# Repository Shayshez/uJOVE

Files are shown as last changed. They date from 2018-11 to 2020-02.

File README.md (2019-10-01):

# uJOVE
# CC BY-NC-SA 4.0
## Micro version of JOVE - Multimode filter, originally by System 80
## Warning for DIY beginners - this project is a hard to build with dense PCB and low pitch ic's which requires experience in SMD soldering.
### If you care about this project - DO NOT SELL ASSEMBLED MODULES, Build only for your own use!

Interactive BOM: http://diy.plum-audio.com/projects/uJove/iBom/

Plum Audio uJove is 8hp version of Jove - Multimode filter By System 80 that is inspired by the Roland Jupiter 6 filter.

uJuve is exactly the same circuit as the original 14 hp Juve with the same amazing sound. 

2 extra modifications have been added to increase the sound variety:

1. When no jack is plugged in to input 2 Positive feedback from the output to input 2 is activated. the feedback level can be controlled by LEVEL 2 knob.
2. Input 2 level knob can add 6dB of gain, 0dB on the middle, +6dB (clipping) when fully clockwise. 

4 Leds of the original 14 hp Jove replaced by one RGB Led

Modes colours:
RED - LP24 , ORANGE - LP12 , BLUE - BP , GREEN - HP

### About Positive Feedback:
Resonance = inverted feedback 

Positive feedback should distort the signal.

In LP2/4 modes (red/orange) the positive feedback alone can make pulses.

it’s better to mix between positive and negative feedback to achieve distorted worm sound.
Also try to use input 2 in LP modes and the positive feedback become clipper (attenuation until middle position of the knob and clipping from middle position)

The positive feedback sounds much better in BP/HP modes (blue/green) to achive great distortion.

uJove is available only as DIY project, for pcb's and panels: https://pushermanproductions.com/product/plum-audio-ujove-pcb-and-8hp-aluminium-panel/

Assembling Video (Part 1): https://www.youtube.com/watch?v=_F6PMT1OO5I

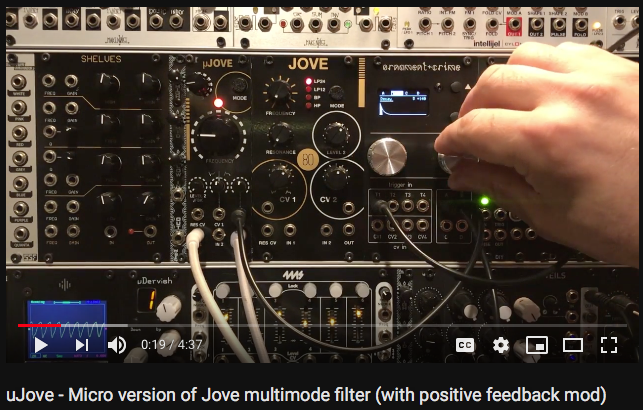
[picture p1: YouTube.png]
uJove at YouTube (https://youtu.be/qpCmzDNtNPw)


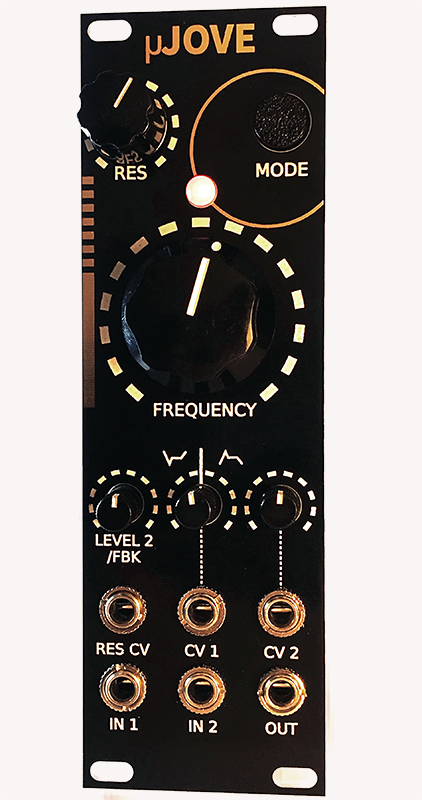
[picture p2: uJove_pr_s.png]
Image of uJOVE


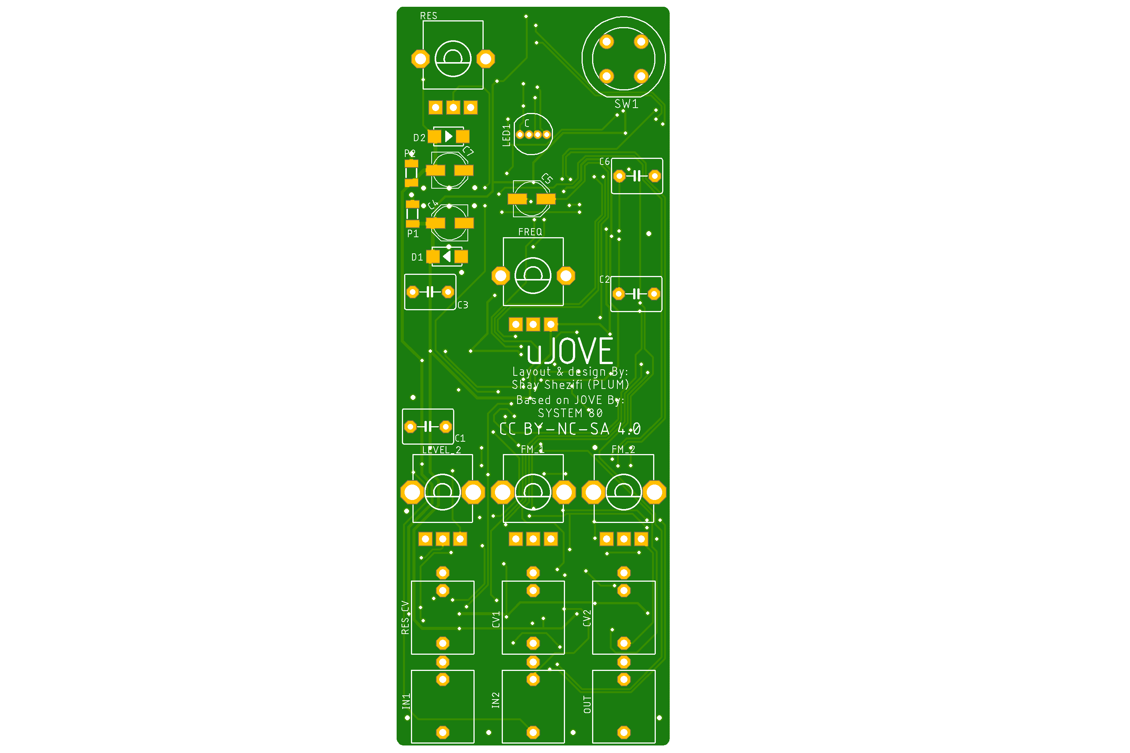
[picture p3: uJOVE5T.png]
Image of uJOVE


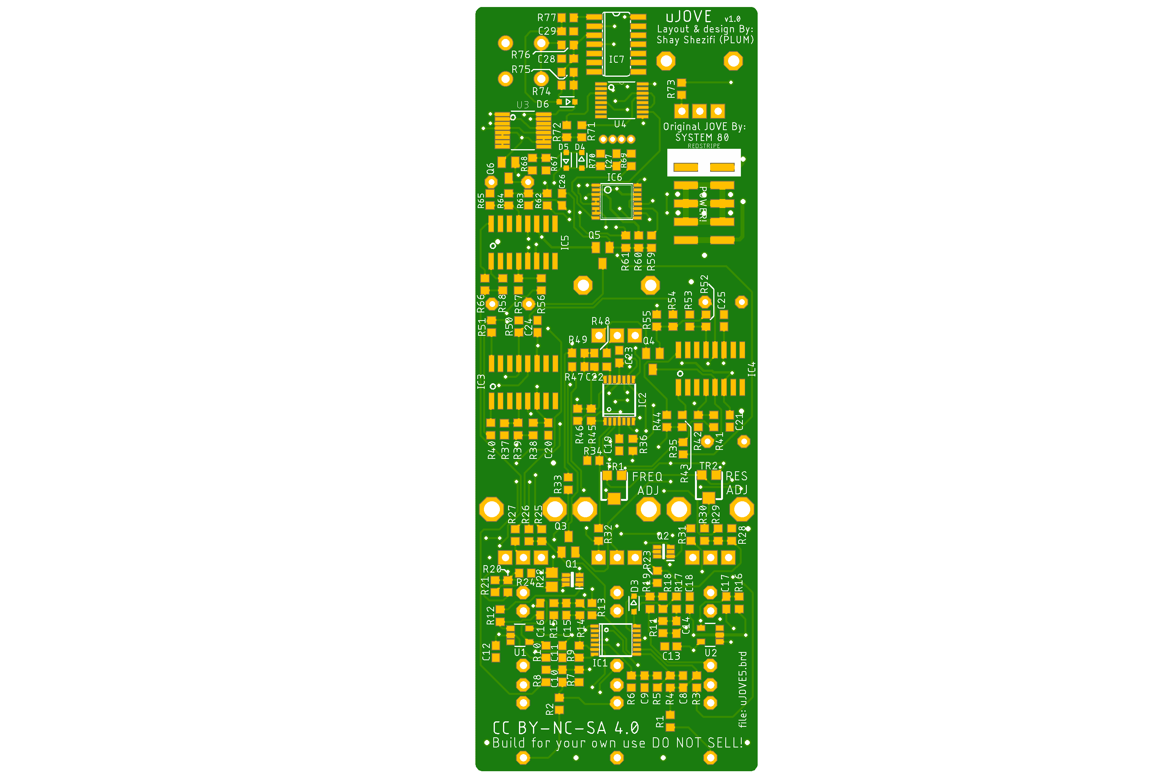
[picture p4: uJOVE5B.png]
Image of uJOVE


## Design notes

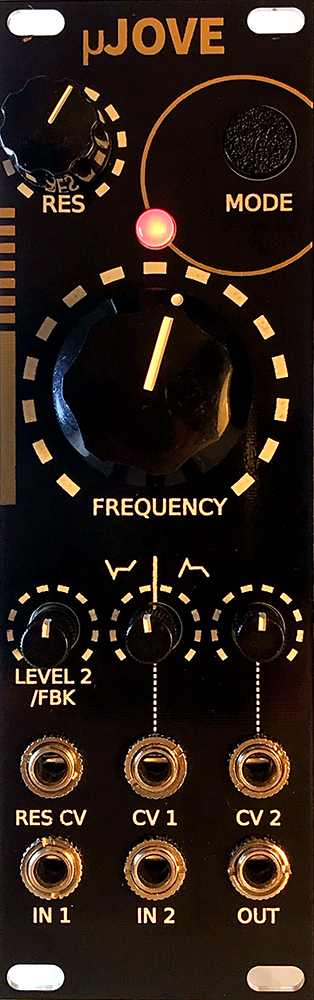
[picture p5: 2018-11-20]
uJove_mg.png

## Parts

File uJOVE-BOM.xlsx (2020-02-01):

 | THIS BOM IS FOR BOARD V1.2
 | Interactive BOM: http://diy.plum-audio.com/projects/uJove/iBom/
Qty | Parts | Value | Device | Package | Mouser referance | Description
 | CAPS
2 | C17, C28 | 4.7pF | C-USC0603 | C0603 | CC0603CRNPO9BN4R7 | CAPACITOR, American symbol
4 | C10, C12, C16, C24 | 22pF | C-USC0603 | C0603 | C0603C220J5G7411 | CAPACITOR, American symbol
2 | C11, C29 | 33pF | C-USC0603 | C0603 | C0603C330J5GACTU | CAPACITOR, American symbol
2 | C19, C18 | 47pF | C-USC0603 | C0603 | C0603C470J5GACTU | CAPACITOR, American symbol
12 | C8, C9, C13, C14, C15, C20, C21, C22, C23, C25, C26, C27 | 100n | C-USC0603 | C0603 | C0603C104M5RACTU | CAPACITOR, American symbol
2 | C30, C31 | 0.47uF | C-USC0603 | C0603 | CGA3E3X5R1H474MB | CAPACITOR, American symbol
1 | C5 | 10uF | CPOL-USC | PANASONIC_C | UUQ1E100MCL1GB | POLARIZED CAPACITOR, American symbol
2 | C4, C7 | 10uF | CPOL-USC | PANASONIC_C | EEE-1EA100SR | POLARIZED CAPACITOR, American symbol
4 | C1, C2, C3, C6 | 330pF | C5/5 | C5B5 | PFR5331J100J11L4 | Polypropylene FILM CAPACITOR 5mm
 | RESISTORS
2 | R76, R77 | 330 | R-US_R0603 | R0603 | RC0603FR-07330RL | RESISTOR, American symbol
6 | R37, R42, R50, R53, R58, R66 | 560 | R-US_R0603 | R0603 | RC0603FR-07560RL | RESISTOR, American symbol
1 | R24 | 820 | R-US_R0603 | R0603 | RC0603FR-07820RL | RESISTOR, American symbol
2 | R2, R28 | 1.0k | R-US_R0603 | R0603 | RC0603FR-071KL | RESISTOR, American symbol
2 | R12, R31 | 1.5k | R-US_R0603 | R0603 | RC0603FR-071K5L | RESISTOR, American symbol
1 | R21 | 1.8k | R-US_R0603 | R0603 | RC0603FR-071K8L | RESISTOR, American symbol
1 | R33 | 4.7k | R-US_R0603 | R0603 | RC0603FR-074K7L | RESISTOR, American symbol
1 | R20 | 5.6k | R-US_R0603 | R0603 | RC0603FR-105K6L | RESISTOR, American symbol
1 | R6 | 8.2k | R-US_R0603 | R0603 | RC0603FR-078K2L | RESISTOR, American symbol
5 | R60, R63, R67, R72, R73 | 10k | R-US_R0603 | R0603 | RC0603FR-0710KL | RESISTOR, American symbol
6 | R40, R43, R44, R51, R56, R59 | 18k | R-US_R0603 | R0603 | RC0603FR-0718KL | RESISTOR, American symbol
7 | R13, R15, R38, R55, R61, R70, R75 | 33k | R-US_R0603 | R0603 | RC0603FR-0733KL | RESISTOR, American symbol
5 | R3, R4, R5, R49, R68 | 47k | R-US_R0603 | R0603 | RC0603FR-0747KL | RESISTOR, American symbol
3 | R26, R35, R71 | 56k | R-US_R0603 | R0603 | RC0603FR-0756KL | RESISTOR, American symbol
6 | R39, R41, R52, R54, R57, R65 | 68k | R-US_R0603 | R0603 | RC0603FR-0768KL | RESISTOR, American symbol
17 | R1, R8, R9, R11, R14, R17, R18, R19, R27, R32, R34, R36, R45, R62, R64, R69, R74 | 100k | R-US_R0603 | R0603 | RC0603FR-07100KL | RESISTOR, American symbol
1 | R29 | 110k | R-US_R0603 | R0603 | RC0603FR-07110KL | RESISTOR, American symbol
1 | R23 | 150k | R-US_R0603 | R0603 | RC0603FR-07150KL | RESISTOR, American symbol
2 | R47, R48 | 200k | R-US_R0603 | R0603 | RC0603FR-07200KL | RESISTOR, American symbol
1 | R25 | 270k | R-US_R0603 | R0603 | RC0603FR-07270KL | RESISTOR, American symbol
1 | R7 | 330k | R-US_R0603 | R0603 | RC0603FR-07330KL | RESISTOR, American symbol
1 | R46 | 680K | R-US_R0603 | R0603 | RC0603FR-07680KL | RESISTOR, American symbol
1 | R30 | 1.0M | R-US_R0603 | R0603 | RC0603FR-071ML | RESISTOR, American symbol
2 | R10, R16 | 1.5M | R-US_R0603 | R0603 | RC0603FR-071M5L | RESISTOR, American symbol
1 | R22 | 10k NTC | R-US_R0805 | R0805 | NCP21XV103J03RA | RESISTOR, American symbol
 | Note1: R71 & R72 = led brightness, R71 for green, R72 for red & blue.
 | Note2: R3 = Gain of input 2 and feadback, 47k for 0dB at pot middle position and +6db clipping at fully clockwise, it can be between 47K-100K (100k = without gain, 0dB at fully clockwise)
 | DIODES / TRANSISTORS
2 | P1, P2 | PTCSMD | PTCSMD (or 4.7R 1206 resistor) | PTC-1206 | 1206L035/16YR | Resettable Fuse PTC
4 | D3, D4, D5, D6 | 1N914BWS | DIODE-SOD323-R | SOD323-R | 512-1N914BWS | DIODE
2 | D1, D2 | S1BB | DIODE-GEN-PURPOSE-1KV-1A(DO-214AC) | DO-214AC | 621-S1BB-F | 304010013
2 | Q1, Q2 | BCM857BS | BCM857BS | SOT65P210X110-6N | BC857BS-7-F | NEXPERIA - BCM857BS - TRANSISTOR, MATCHED, SOT-363
4 | Q3, Q4, Q5, Q6 | MMBFJ112MMBFJ112 | MMBFJ112MMBFJ112 | SOT23 | 512-MMBFJ112 | * NO STOCK AT MOUSER, CAN BE FOUND HERE: https://www.aliexpress.com/item/FREE-SHIPPING-SOT23-GR-MMBFJ112-20PCS-in-Stock/32314708542.html
 | IC'S
1 | IC8 | 40106D | 40106D | SO14 | CD40106BM96 | Hex SCHMITT TRIGGER
1 | U4 | CD4052BPWR | CD4052BPWR | SOP65P640X120-16N | CD4052BPWR | single 8-Channel multiplexer
2 | U1, U2 | TS321ILT | TS321IDBV | SOT23-5 | TS321ILT
1 | IC3 | TL074TSSOP14 | TL074TSSOP14 | TSSOP14 | TL074CPWR | OP AMP
2 | IC1, IC2 | TL072 TSSOP8 | TL072TL072_TSSOP8 | TSSOP8 | TL072CPWR | OP AMP
1 | IC7 | DQDG409DQ-T1-E3 | DG409DQ-T1-E3 | TSSOP16 | DG409DQ-E3 | ANALOG MULTIPLEXER
3 | IC4, IC5, IC6 | OTA_LM13700M | OTA_LM13700M | OTA_SO16 | LM13700MX/NOPB | Dual OTA with buffers
1 | U3 | CD4027BPWRPW16-M | CD4027BPWRPW16-M | PW16-M | CD4027BPWR
 | TH / MISC
2 | TR1, TR2 | 100K | TC33X-2-104E | TC33X-2 | TC33X-2-104E | Cermet 3mm SMT trimmer,0.1W 100k Bourns TC33 Series SMD Cermet Trimmer Resistor with Solder Pad Terminations, 100k 25% 1/10W 250ppm/C Top Adjust
1 | LED1 | LED-TRICOLOR-THROUGHHOLE | LED-TRICOLOR-THROUGHHOLE | LED-TRICOLOR-THROUGHHOLE | COMON CATHODE | https://www.aliexpress.com/item/50-pcs-LED-5mm-RGB-Diffused-COMMON-Anode-50-pcs-LED-5mm-RGB-Diffused-COMMON-Cathode/32666299281.html
1 | SW1 | D6R | D6R | D6R | 611-D6R90LFS (black) or Thonk: https://www.thonk.co.uk/shop/radio-music-switch/ | C&K D6R (for other colors: White = D6R00F1LFS, Gray = D6R10F1LFS, Yellow = D6R30F1LFS, Red = D6R40F1LFS, Green = D6R50F1LFS, Blue = D6R60F1LFS)
6 | CV1, CV2, IN1, IN2, OUT, RES_CV | PJ301_PJ301_THONKICONN | THONKICONN | PJ301_WQP_PJ_301M6 | https://www.thonk.co.uk/shop/thonkiconn/
3 | FM_1, FM_2, LEVEL_2 | B50k | Song Huei Tall trimmer 9mm |  | https://www.thonk.co.uk/shop/ttpots/
2 | FREQ, RES | B50k | Alpha 9mm Pot |  | https://www.thonk.co.uk/shop/alpha-9mm-pots-vertical-t18/
1 | POWER! | SMD POWER HEADER | POWER | 2X05_SMT_HEADER | https://www.ebay.com/itm/10pcs-2-40Pin-SMD-SMT-2-40Pin-Male-Double-Row-Pin-Header-Connector-2-54MM-Pitch/182570982083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
 | Big knob (Frequancy) | Large Black - Erica Plastic Knob |  |  | https://www.thonk.co.uk/shop/erica-knobs-6-35mm-shaft/
 | Resonance Knob | 1900h |  |  | https://www.thonk.co.uk/shop/1900h-t18/

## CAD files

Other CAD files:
Panel/uJOVE_PANEL.dwg

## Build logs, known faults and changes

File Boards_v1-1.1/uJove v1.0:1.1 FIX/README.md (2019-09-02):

# uJOVE - FIX Board for the output of uJove v1.0/1.1 bosrds.

Installation Video: https://youtu.be/Y7jof6UY3rQ

In some cases, in uJove boards v1.0 / 1.1
there is a bleeding problem of low unfiltered signal
This problem is caused by crosstalk  between the input to the output inside IC1
uJove FIX board adds separate dedicated opamp for the output And fixes the problem

BOM:
1 uJove Output FIX for board v1.0/1.1 PCB

1 TL072 smd

2 100nF 0603 cap

7 Legs of Through Hole resistors

2 Standoffs Spacers

Installation instreactions:
1. Remove R2, R7, R8, C10 From uJove board
2. You can use those components in the FIX board
3. Cut trace from PIN 1 of IC1 and bridge PIN 1 to PIN 2
4. Use TH legs to connect between the boards.

Connection points on uJove board:
-12V from C12 TOP

+12V from C11 TOP

GND from Out/In2 jacks (GND pins)

In from R8 Bottom 

Out from R2 Bottom

Feedback from In2 jack (switch pin)

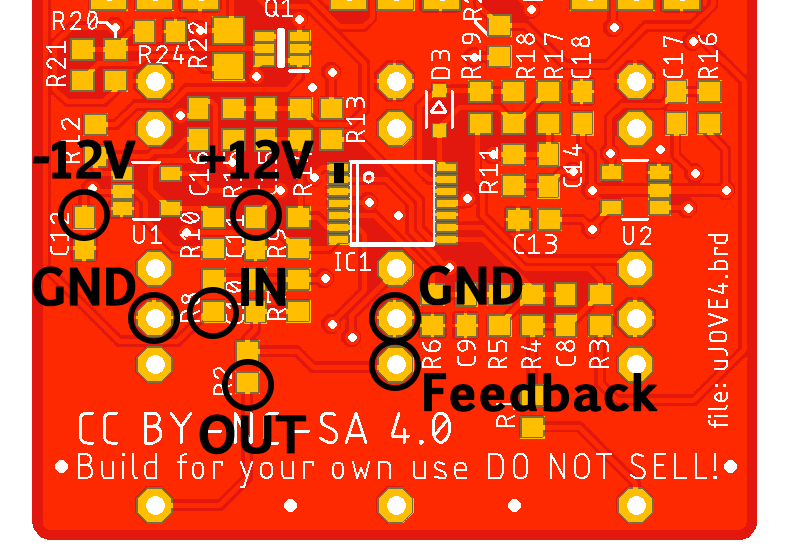
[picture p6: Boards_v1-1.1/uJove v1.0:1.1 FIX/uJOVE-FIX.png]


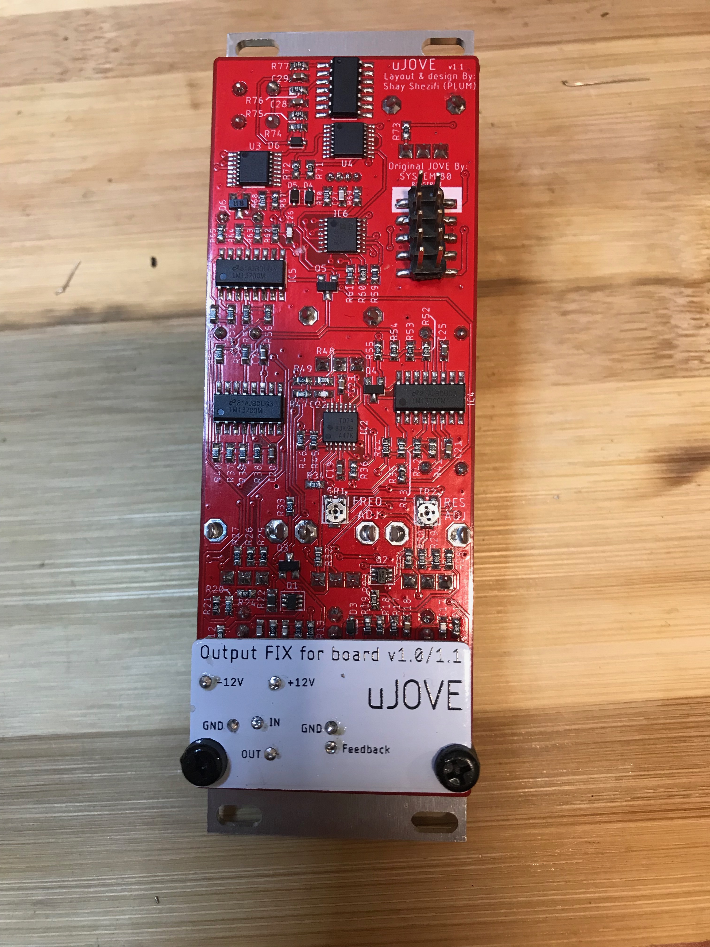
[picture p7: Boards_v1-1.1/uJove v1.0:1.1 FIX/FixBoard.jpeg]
Image of uJOVE


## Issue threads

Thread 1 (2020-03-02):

Led Colors (Modes)

epijdemie, 2020-03-02:
Alan Shai :-)

I have a question: i just finished this module (nice one btw!) and i cycle through the modes but my LED shows BLUE - BLUE - GREEN - RED ... there is no orange.. its 2 times blue (maaaaaybe slight difference, but certainly no orange). I have the LED according to BOM and i inserted it according to the silkscreen.
What went wrong?

m503226, 2025-03-28:
Hi - I have exactly this problem. Did you ever find the solution?

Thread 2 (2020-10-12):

BOM questions (led size and pots)

skinpop, 2020-10-12:
The interactive BOM doesn't specify whether the LED is 3mm or 5mm.

Is there a difference between OG-POTS_ALPS_POT_VERTICAL and OG-POTS_ALPS_POT_VERTICAL_PS? Are these pots ok: https://www.thonk.co.uk/shop/alpha-9mm-pots/
Should they be linear, exponential? Maybe I'm missing something but the bom seems to lack info.

myraz, 2020-10-21:
@skinpop When looking at the BOM, it says B50K. The B is for linear.
Unfortunately I can't answer your first question about the pots.

skinpop, 2020-12-14:
Thank you for commenting.
Where are you seeing that B? For me it just says 50k.

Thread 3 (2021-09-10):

TL072 TSSOP8 out of stock (IC1 IC2 on pcb)

lancerotti, 2021-09-10:
Hello,
as these seem to be out of stock at many vendors, is there any replacement you'd suggest? 082s also difficult to get, apparently. Trying to navigate through the opamps equivalents but don't wanna make the wrong choice for this actual application.
thank you in advance for the help
Nicola

Closed 2021-09-15.

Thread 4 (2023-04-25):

Missing pad in the gerber file

unbalancedbeats, 2023-04-25:
Hi!
The red stripe pads are missing in the geber files. Is this normal?
Thanks for your time and
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
 regards.[

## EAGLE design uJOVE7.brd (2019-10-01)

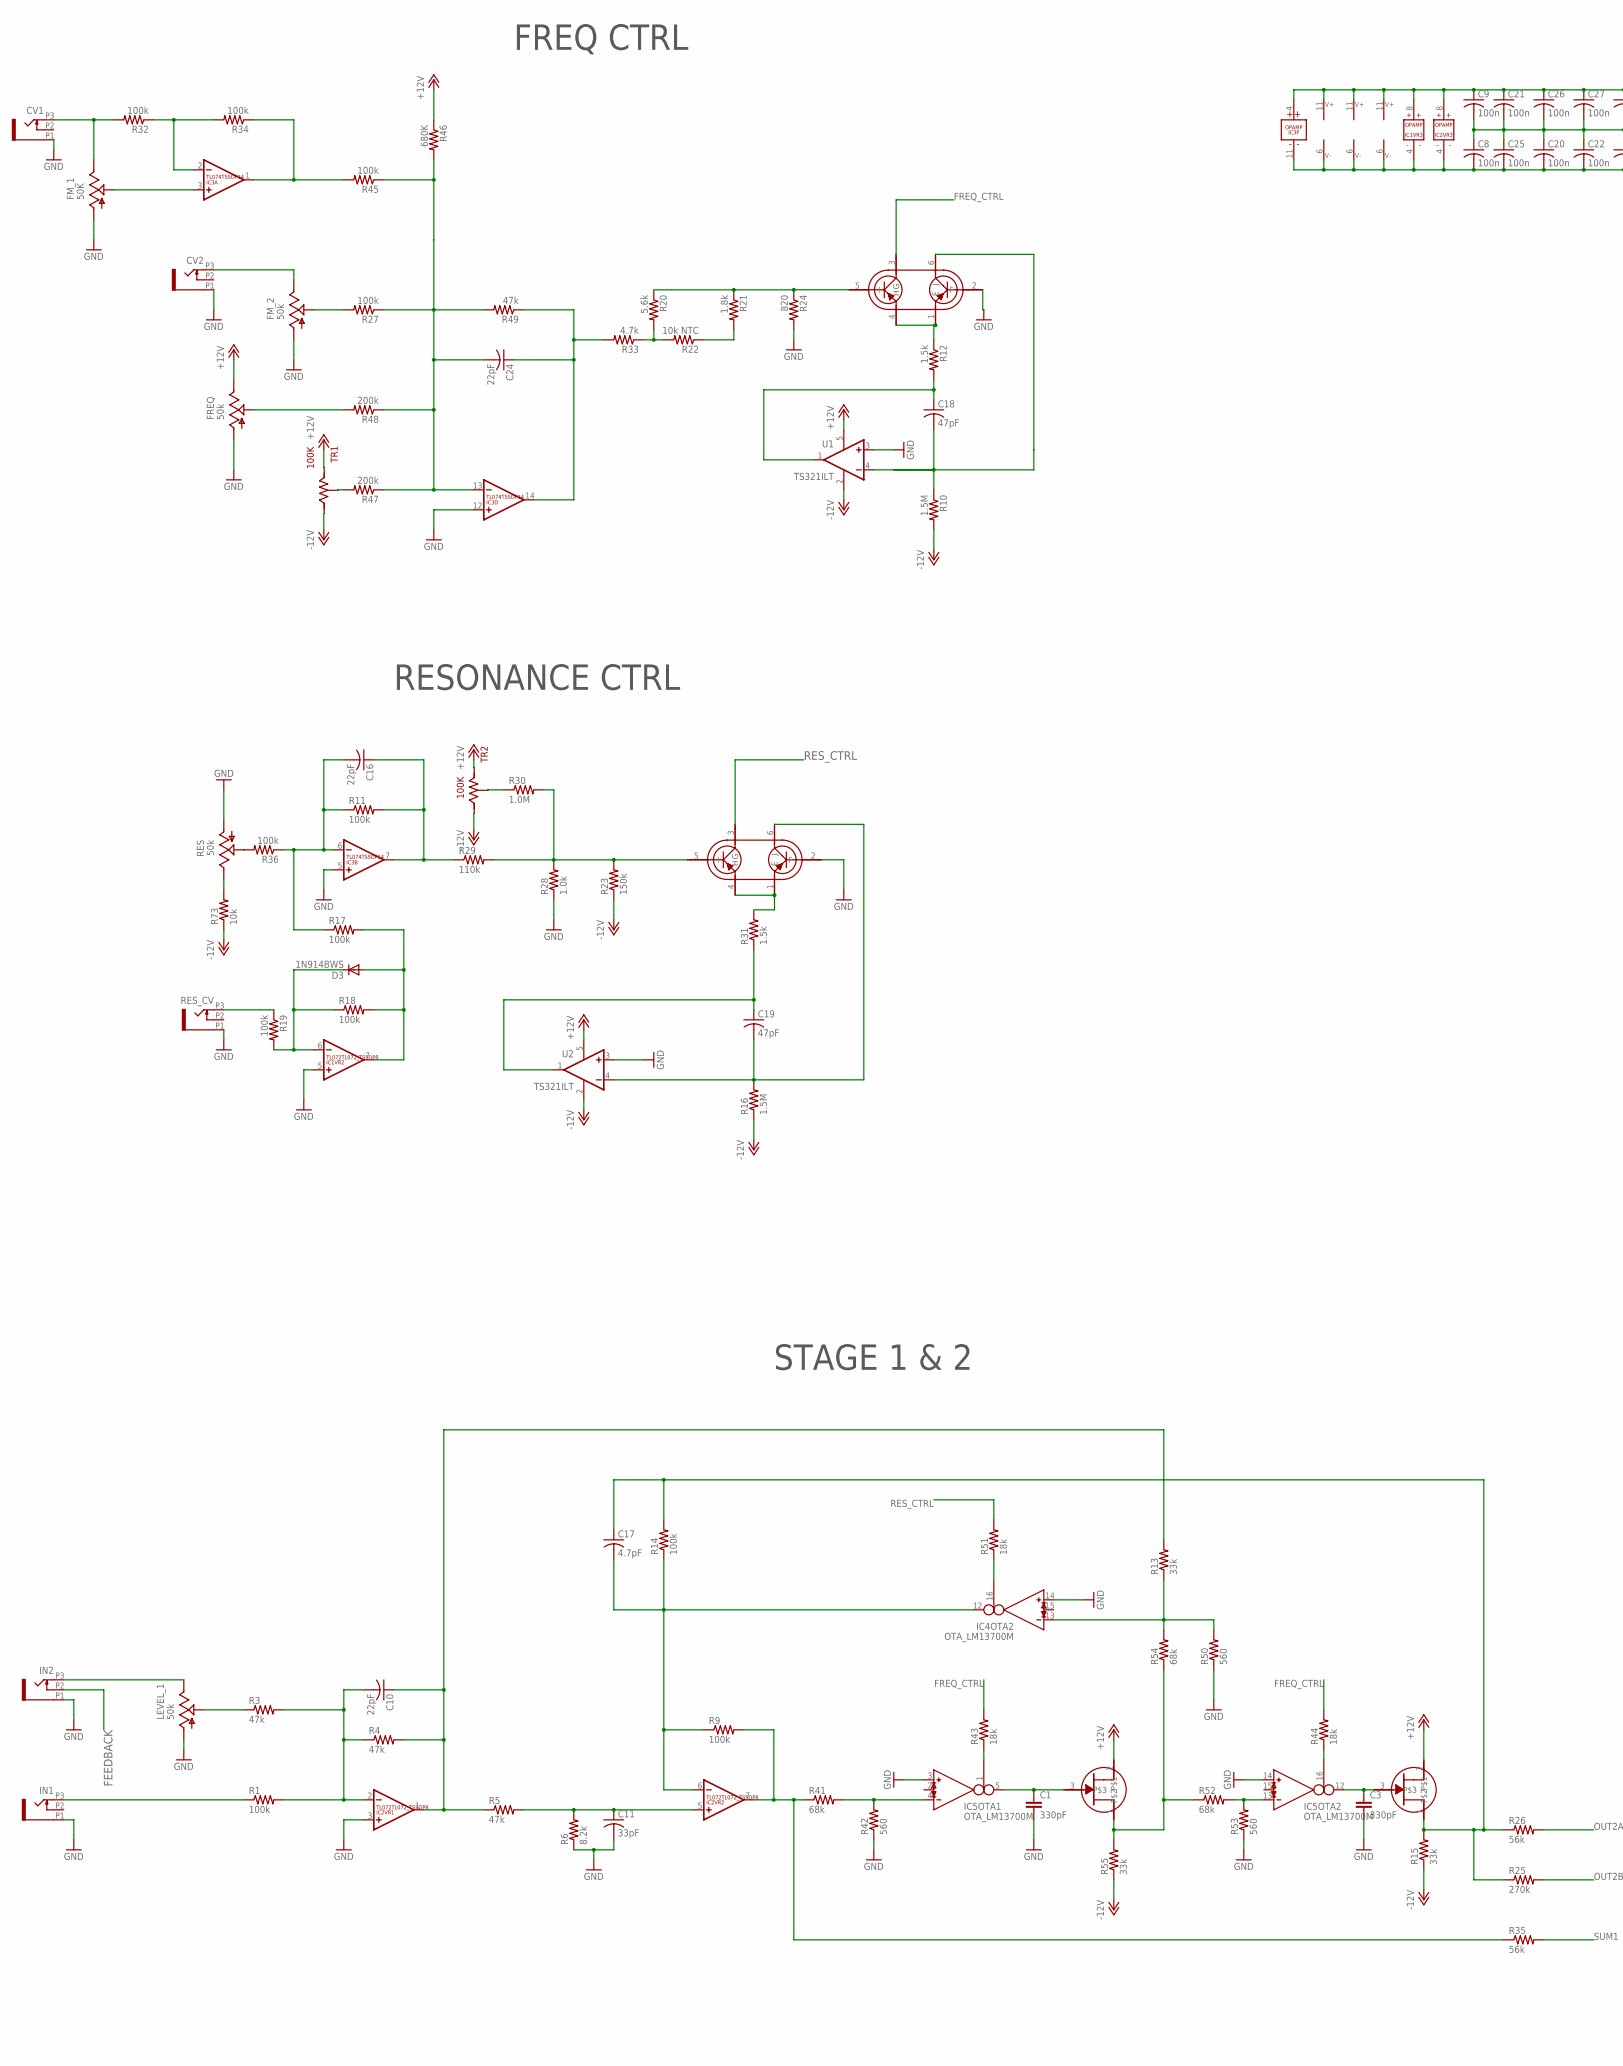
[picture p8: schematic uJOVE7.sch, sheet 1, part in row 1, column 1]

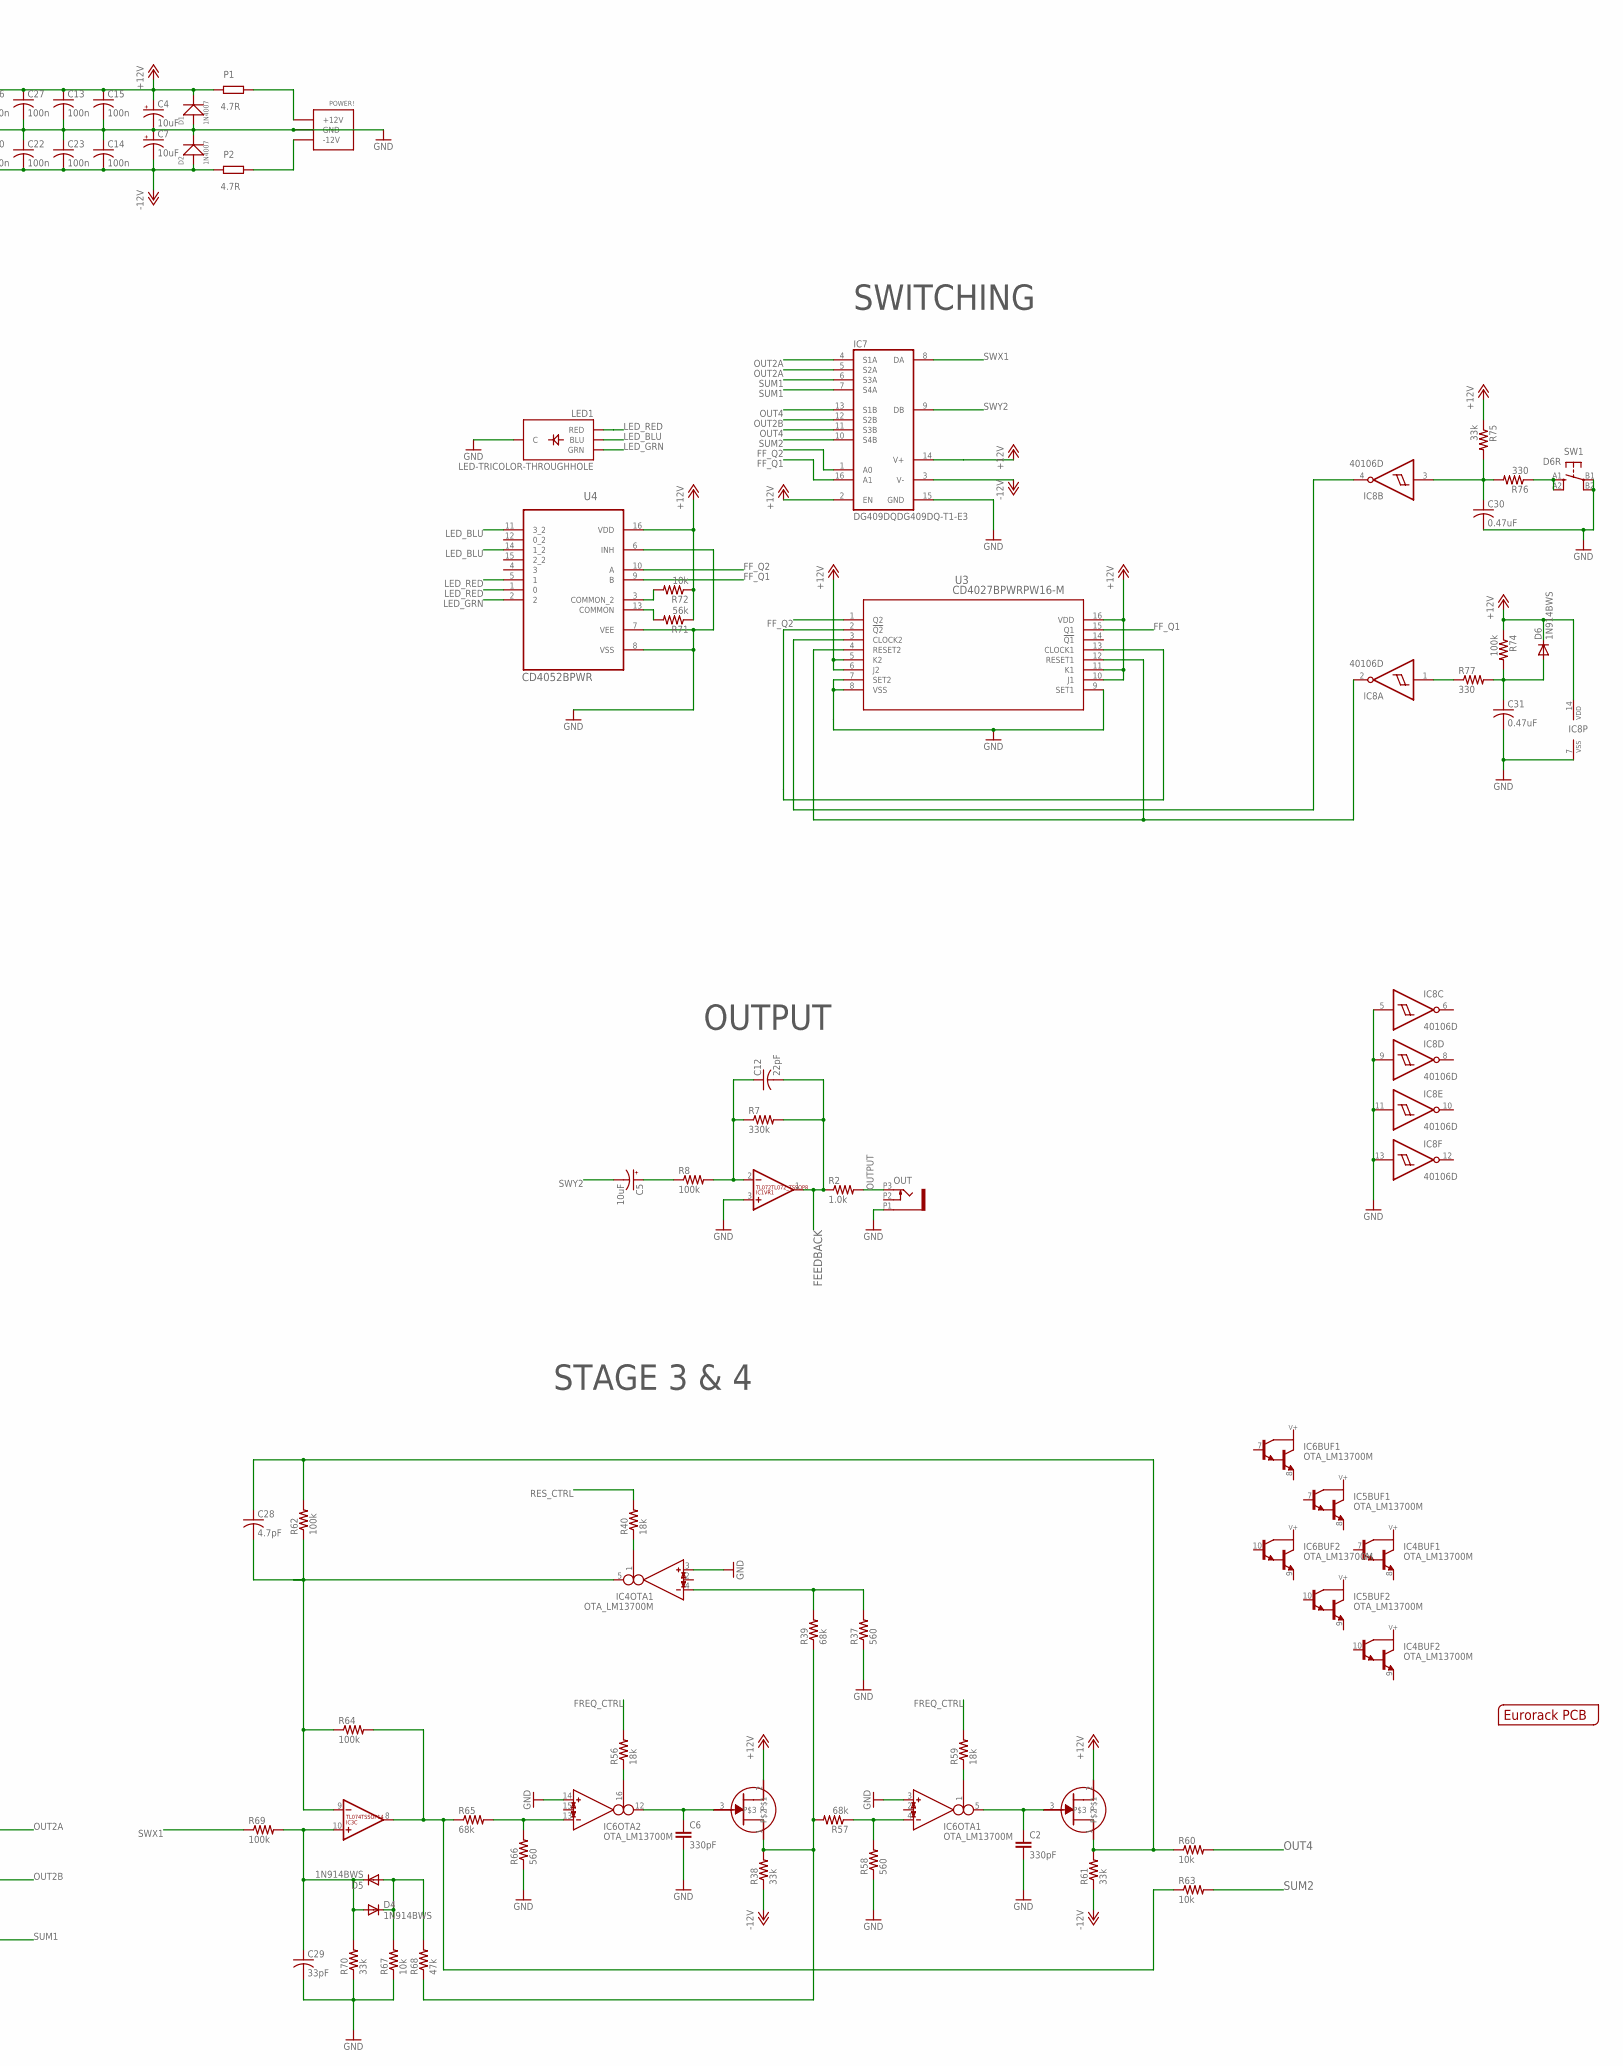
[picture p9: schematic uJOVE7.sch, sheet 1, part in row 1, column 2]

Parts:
C1, C2, C3, C6: 330pF; C5B5
C4, C5, C7: 10uF; PANASONIC_C
C8, C9, C13, C14, C15, C20, C21, C22, C23, C25, C26, C27: 100n; C0603
C10, C12, C16, C24: 22pF; C0603
C11, C29: 33pF; C0603
C17, C28: 4.7pF; C0603
C18, C19: 47pF; C0603
C30, C31: 0.47uF; C0603
CV1, CV2: OG-PJ301_PJ301_THONKICONN; OG-PJ301_WQP_PJ_301M6_NO_HOLE
D1, D2: 1N4007; DO-214AC
D3, D4, D5, D6: 1N914BWS; SOD323-R
FM_1: 50K; OG-POTS_ALPS_POT_VERTICAL
FM_2: 50k; OG-POTS_ALPS_POT_VERTICAL
FREQ: 50k; OG-POTS_ALPS_POT_VERTICAL_PS
IC1, IC2: TL072TL072_TSSOP8; TL072_TSSOP8
IC3: TL074TSSOP14; TSSOP14
IC4, IC5, IC6: OTA_LM13700M; OTA_SO16
IC7: DG409DQDG409DQ-T1-E3; TSSOP16
IC8: 40106D; SO14
IN1, IN2: OG-PJ301_PJ301_THONKICONN; OG-PJ301_WQP_PJ_301M6_NO_HOLE
LED1: LED-TRICOLOR-THROUGHHOLE
LEVEL_1: 50k; OG-POTS_ALPS_POT_VERTICAL
OUT: OG-PJ301_PJ301_THONKICONN; OG-PJ301_WQP_PJ_301M6_NO_HOLE
P1, P2: 4.7R; R1206
PCB1: EURORACK_PCB; EURORACK8HPPCB-S
POWER!: POWER_SIMPLE; 2X05_SMT_HEADER
Q1, Q2: BCM857BS; SOT65P210X110-6N
Q3, Q4, Q5, Q6: MMBFJ112MMBFJ112; SOT23
R1, R8, R9, R11, R14, R17, R18, R19, R27, R32, R34, R36, R45, R62, R64, R69, R74: 100k; R0603
R2, R28: 1.0k; R0603
R3, R4, R5, R49, R68: 47k; R0603
R6: 8.2k; R0603
R7: 330k; R0603
R10, R16: 1.5M; R0603
R12, R31: 1.5k; R0603
R13, R15, R38, R55, R61, R70, R75: 33k; R0603
R20: 5.6k; R0603
R21: 1.8k; R0603
R22: 10k NTC; R0805
R23: 150k; R0603
R24: 820; R0603
R25: 270k; R0603
R26, R35, R71: 56k; R0603
R29: 110k; R0603
R30: 1.0M; R0603
R33: 4.7k; R0603
R37, R42, R50, R53, R58, R66: 560; R0603
R39, R41, R52, R54, R57, R65: 68k; R0603
R40, R43, R44, R51, R56, R59: 18k; R0603
R46: 680K; R0603
R47, R48: 200k; R0603
R60, R63, R67, R72, R73: 10k; R0603
R76, R77: 330; R0603
RES: 50k; OG-POTS_ALPS_POT_VERTICAL_PS
RES_CV: OG-PJ301_PJ301_THONKICONN; OG-PJ301_WQP_PJ_301M6_NO_HOLE
SW1: D6R
TR1, TR2: 100K; TC33X-2
U1, U2: TS321ILT; SOT23-5
U3: CD4027BPWRPW16-M; PW16-M
U4: CD4052BPWR; SOP65P640X120-16N

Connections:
+12V: C4.+, C9.1, C13.1, C15.1, C21.1, C26.1, C27.1, D1.2 (-), D6.C, FREQ.P$1 (E), IC1.8 (V+), IC2.8 (V+), IC3.4 (V+), IC4.11 (V+), IC5.11 (V+), IC6.11 (V+), IC7.2 (EN), IC7.14 (V+), IC8.14 (VDD), P1.1, Q3.2, Q4.2, Q5.2, Q6.2, R46.1, R71.1, R72.1, R74.1, R75.1, TR1.1, TR2.1, U1.5 (V+), U2.5 (V+), U3.5 (K2), U3.6 (J2), U3.10 (J1), U3.11 (K1), U3.16 (VDD), U4.16 (VDD)
-12V: C7.-, C8.2, C14.2, C20.2, C22.2, C23.2, C25.2, D2.1 (+), IC1.4 (V-), IC2.4 (V-), IC3.11 (V-), IC4.6 (V-), IC5.6 (V-), IC6.6 (V-), IC7.3 (V-), P2.1, R10.2, R15.1, R16.1, R23.1, R38.1, R55.1, R61.1, R73.1, TR1.3, TR2.3, U1.2 (V-), U2.2 (V-)
FEEDBACK: C12.2, IC1.1 (OUT), IN2.P2 (2), R2.1, R7.2
FF_Q1: IC7.16 (A1), U3.15 (Q1), U4.9 (B)
FF_Q2: IC7.1 (A0), U3.1 (Q2), U4.10 (A)
FREQ_CTRL: Q1.3 (G), R43.2, R44.2, R56.2, R59.2
GND: C1.2, C2.2, C3.2, C4.-, C6.2, C7.+, C8.1, C9.2, C11.2, C13.2, C14.1, C15.2, C20.1, C21.2, C22.1, C23.1, C25.1, C26.2, C27.2, C29.2, C30.2, C31.2, CV1.P1 (1), CV2.P1 (1), D1.1 (+), D2.2 (-), FM_1.P$3 (A), FM_2.P$3 (A), FREQ.P$3 (A), IC1.3 (+IN), IC1.5 (+IN), IC2.3 (+IN), IC3.5 (+IN), IC3.12 (+IN), IC4.3 (IN_P), IC4.14 (IN_P), IC5.3 (IN_P), IC5.14 (IN_P), IC6.3 (IN_P), IC6.14 (IN_P), IC7.15 (GND), IC8.5 (I), IC8.7 (VSS), IC8.9 (I), IC8.11 (I), IC8.13 (I), IN1.P1 (1), IN2.P1 (1), LED1.GND (C), LEVEL_1.P$3 (A), OUT.P1 (1), POWER!.3 (GND), POWER!.4 (GND), POWER!.5 (GND), POWER!.6 (GND), POWER!.7 (GND), POWER!.8 (GND), Q1.2 (F), Q2.2 (F), R6.1, R24.2, R28.1, R37.1, R42.1, R50.1, R53.1, R58.1, R66.1, R67.1, R70.1, RES.P$3 (A), RES_CV.P1 (1), SW1.B1, SW1.B2 (P1), U1.3 (+IN), U2.3 (+IN), U3.7 (SET2), U3.8 (VSS), U3.9 (SET1), U4.6 (INH), U4.7 (VEE), U4.8 (VSS)
LED_BLU: LED1.BLU, U4.11 (3_2), U4.14 (1_2)
LED_GRN: LED1.GRN, U4.2
LED_RED: LED1.RED, U4.1 (0), U4.5 (1)
unnamed: P1.2, POWER!.9 (+12V), POWER!.10 (+12V)
unnamed: P2.2, POWER!.1 (-12V), POWER!.2 (-12V)
unnamed: IN1.P3 (3), R1.1
unnamed: C10.2, IC2.2 (-IN), R1.2, R3.2, R4.1
unnamed: IN2.P3 (3), LEVEL_1.P$1 (E)
unnamed: LEVEL_1.P$2 (S), R3.1
unnamed: C10.1, IC2.1 (OUT), R4.2, R5.1, R13.2
unnamed: C11.1, IC2.5 (+IN), R5.2, R6.2
unnamed: IC2.7 (OUT), R9.2, R35.1, R41.1
unnamed: C17.2, IC2.6 (-IN), IC4.12 (OUT), R9.1, R14.1
unnamed: IC5.4 (IN_N), R41.2, R42.2
unnamed: IC5.1 (I_BIAS), R43.1
unnamed: C1.1, IC5.5 (OUT), Q4.3
unnamed: IC5.13 (IN_N), R52.2, R53.2
unnamed: IC4.13 (IN_N), R13.1, R50.2, R54.2
unnamed: IC4.16 (I_BIAS), R51.1
unnamed: C17.1, Q3.1, R14.2, R15.2, R25.1, R26.1
unnamed: Q4.1, R52.1, R54.1, R55.2
unnamed: IC5.16 (I_BIAS), R44.1
unnamed: R73.2, RES.P$1 (E)
unnamed: C3.1, IC5.12 (OUT), Q3.3
unnamed: C5.+, R8.1
unnamed: C12.1, IC1.2 (-IN), R7.1, R8.2
unnamed: C31.1, D6.A, R74.2, R77.2
unnamed: IC3.8 (OUT), R63.1, R64.2, R65.1
unnamed: IC6.4 (IN_N), R57.1, R58.2
unnamed: D4.C, D5.A, R67.2, R68.2
unnamed: C29.1, D4.A, D5.C, IC3.10 (+IN), R69.2, R70.2
unnamed: IC6.13 (IN_N), R65.2, R66.2
unnamed: IC4.4 (IN_N), R37.2, R39.2
unnamed: IC6.16 (I_BIAS), R56.1
unnamed: C6.1, IC6.12 (OUT), Q6.3
unnamed: Q6.1, R38.2, R39.1, R57.2, R68.1
unnamed: IC4.1 (I_BIAS), R40.1
unnamed: C28.2, IC3.9 (-IN), IC4.5 (OUT), R62.1, R64.1
unnamed: R36.2, RES.P$2 (S)
unnamed: IC6.1 (I_BIAS), R59.1
unnamed: C28.1, Q5.1, R60.1, R61.2, R62.2
unnamed: C2.1, IC6.5 (OUT), Q5.3
unnamed: R19.1, RES_CV.P3 (3)
unnamed: D3.C, IC1.6 (-IN), R18.1, R19.2
unnamed: D3.A, IC1.7 (OUT), R17.2, R18.2
unnamed: C16.2, IC3.6 (-IN), R11.1, R17.1, R36.1
unnamed: R30.1, TR2.2
unnamed: C16.1, IC3.7 (OUT), R11.2, R29.1
unnamed: Q2.5 (I), R23.2, R28.2, R29.2, R30.2
unnamed: Q2.1 (E), Q2.4 (H), R31.2
unnamed: C19.2, Q2.6 (J), R16.2, U2.4 (-IN)
unnamed: C19.1, R31.1, U2.1 (OUT)
unnamed: CV1.P3 (3), FM_1.P$1 (E), R32.2
unnamed: IC3.2 (-IN), R32.1, R34.2
unnamed: FM_1.P$2 (S), IC3.3 (+IN)
unnamed: IC3.1 (OUT), R34.1, R45.2
unnamed: C24.2, IC3.13 (-IN), R27.1, R45.1, R46.2, R47.1, R48.1, R49.2
unnamed: CV2.P3 (3), FM_2.P$1 (E)
unnamed: FM_2.P$2 (S), R27.2
unnamed: FREQ.P$2 (S), R48.2
unnamed: R47.2, TR1.2
unnamed: C24.1, IC3.14 (OUT), R33.2, R49.1
unnamed: R20.2, R22.2, R33.1
unnamed: Q1.5 (I), R20.1, R21.1, R24.1
unnamed: R21.2, R22.1
unnamed: C18.2, Q1.6 (J), R10.1, U1.4 (-IN)
unnamed: Q1.1 (E), Q1.4 (H), R12.1
unnamed: C18.1, R12.2, U1.1 (OUT)
unnamed: IC8.1 (I), R77.1
unnamed: C30.1, IC8.3 (I), R75.2, R76.2
unnamed: IC8.2 (O), U3.4 (RESET2), U3.12 (RESET1)
unnamed: IC8.4 (O), U3.3 (CLOCK2)
unnamed: R76.1, SW1.A1 (S), SW1.A2 (S1)
unnamed: U3.2 (!Q2), U3.13 (CLOCK1)
unnamed: R72.2, U4.3 (COMMON_2)
unnamed: R71.2, U4.13 (COMMON)
OUT2A: IC7.4 (S1A), IC7.5 (S2A), R26.2
OUT2B: IC7.12 (S2B), R25.2
OUT4: IC7.11 (S3B), IC7.13 (S1B), R60.2
OUTPUT: OUT.P3 (3), R2.2
RES_CTRL: Q2.3 (G), R40.2, R51.2
SUM1: IC7.6 (S3A), IC7.7 (S4A), R35.2
SUM2: IC7.10 (S4B), R63.2
SWX1: IC7.8 (DA), R69.1
SWY2: C5.-, IC7.9 (DB)

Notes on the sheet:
STAGE 1 & 2
OUTPUT
STAGE 3 & 4
RESONANCE CTRL
FREQ CTRL
SWITCHING

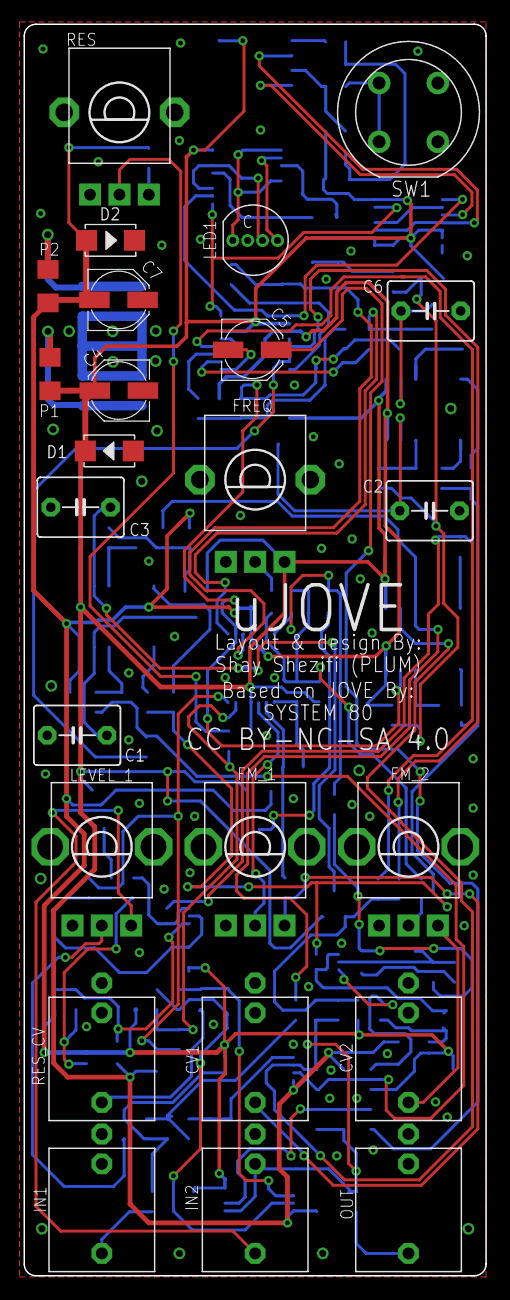
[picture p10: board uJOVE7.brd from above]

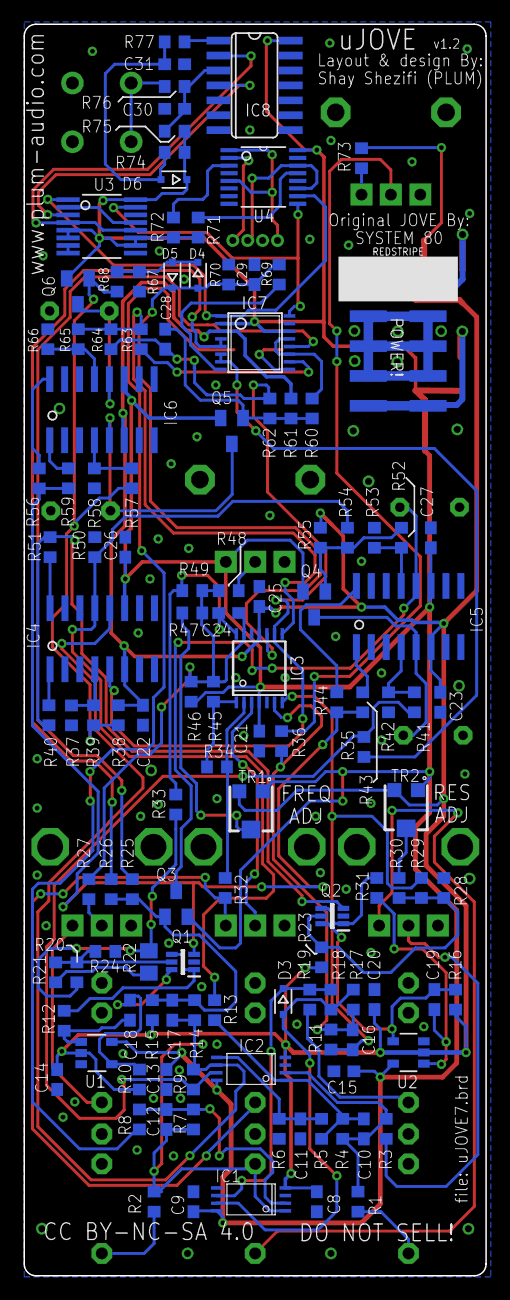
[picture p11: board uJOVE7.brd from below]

Board: 2 copper layers, 39.3 x 106.5 mm, 151 parts (126 on the bottom side), 92 nets.

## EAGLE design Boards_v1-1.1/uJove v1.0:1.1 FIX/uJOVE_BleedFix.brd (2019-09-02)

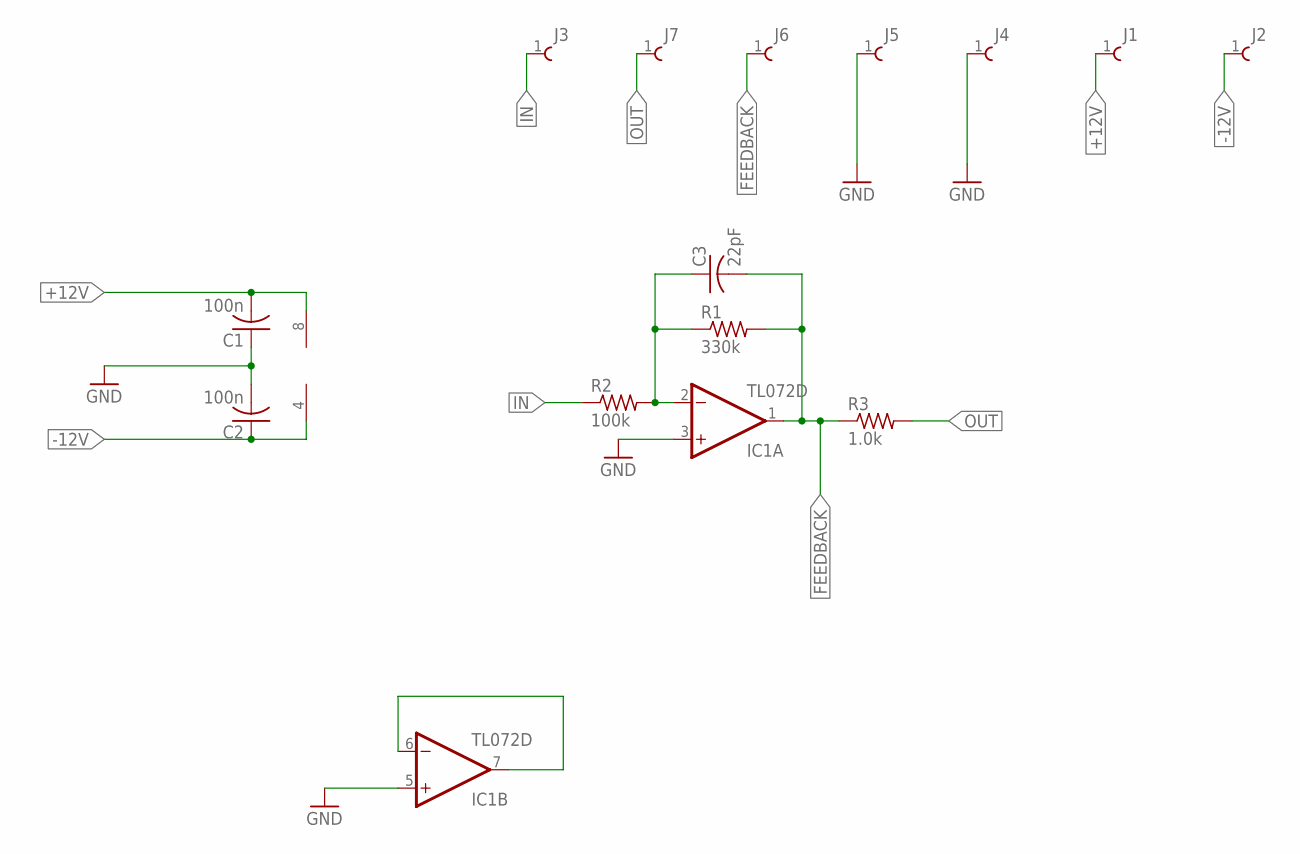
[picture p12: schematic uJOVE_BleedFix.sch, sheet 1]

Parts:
C1, C2: 100n; C0603
C3: 22pF; C0603
IC1: TL072D; SO08
J1, J2, J3, J4, J5, J6, J7: 61300111121
R1: 330k; R0603
R2: 100k; R0603
R3: 1.0k; R0603

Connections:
+12V: C1.2, IC1.8 (V+), J1.1
-12V: C2.1, IC1.4 (V-), J2.1
FEEDBACK: C3.2, IC1.1 (OUT), J6.1, R1.2, R3.1
GND: C1.1, C2.2, IC1.3 (+IN), IC1.5 (+IN), J4.1, J5.1
IN: J3.1, R2.1
unnamed: IC1.6 (-IN), IC1.7 (OUT)
unnamed: C3.1, IC1.2 (-IN), R1.1, R2.2
OUT: J7.1, R3.2

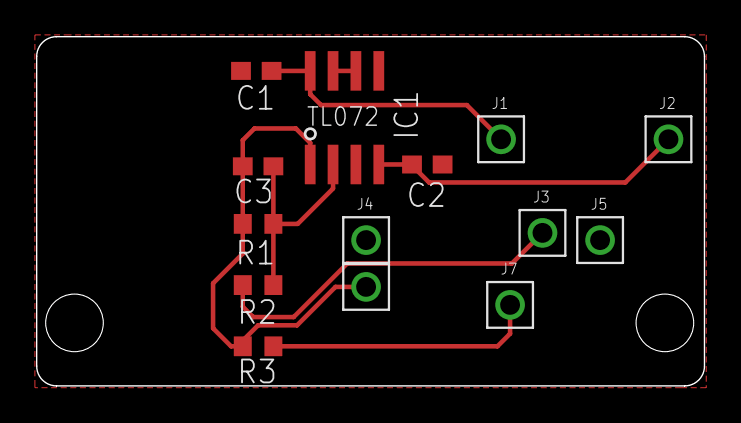
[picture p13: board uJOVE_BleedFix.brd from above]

Board: 2 copper layers, 37.1 x 19.4 mm, 14 parts (0 on the bottom side), 8 nets.

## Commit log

2018-11-20 Initial release
    [uJOVE-BOM.xlsx, uJOVE5.brd, uJOVE5.sch]
2018-11-22 Updated BOM
    [uJOVE-BOM.xlsx]
2018-12-10 Fixed mouser reference
    [uJOVE-BOM.xlsx]
2019-09-02 Output bleed FIX for uJove v1.0/1.1
    [uJOVE_BleedFix.brd, uJOVE_BleedFix.sch]
2019-10-01 Files for boards v1 or v1.1
    [uJOVE-BOM.xlsx, uJOVE5.brd, uJOVE5.sch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]
2019-10-01 Board v1.2
    [uJOVE7.brd, uJOVE7.sch]
2019-10-01 BOM uJove v1.2
    [uJOVE-BOM.xlsx]

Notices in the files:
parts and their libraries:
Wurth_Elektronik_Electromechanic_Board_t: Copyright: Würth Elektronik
